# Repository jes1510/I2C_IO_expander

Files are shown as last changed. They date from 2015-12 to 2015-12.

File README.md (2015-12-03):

# I2C_IO_expander

Designed by Jesse Merritt www.github.com/jes1510 December 2, 2015

This design is free software: you can redistribute it and/or modify it under the terms of the GNU General Public License as published by the Free Software Foundation, either version 3 of the License, or (at your option) any later version.

This program is distributed in the hope that it will be useful, but WITHOUT ANY WARRANTY; without even the implied warranty of MERCHANTABILITY or FITNESS FOR A PARTICULAR PURPOSE. See the GNU General Public License for more details.

You should have received a copy of the GNU General Public License along with this program. If not, see <http://www.gnu.org/licenses/

This is an I2C IO expander board that will add 16 pins of IO to a micro controller over I2C.  The IC used allows up to 8 devices on a bus so they can be daisy chained using common RJ11 (telephone) patch cables, allowing a max of 128 pins of IO.  The address is configurable along with terminations and interrupt destinations.

You can assume that I have no idea what I am doing and therefor am not responsible for any damage or negative consequences for using anything from this project. It may destroy all of your equipment and burn down your house.

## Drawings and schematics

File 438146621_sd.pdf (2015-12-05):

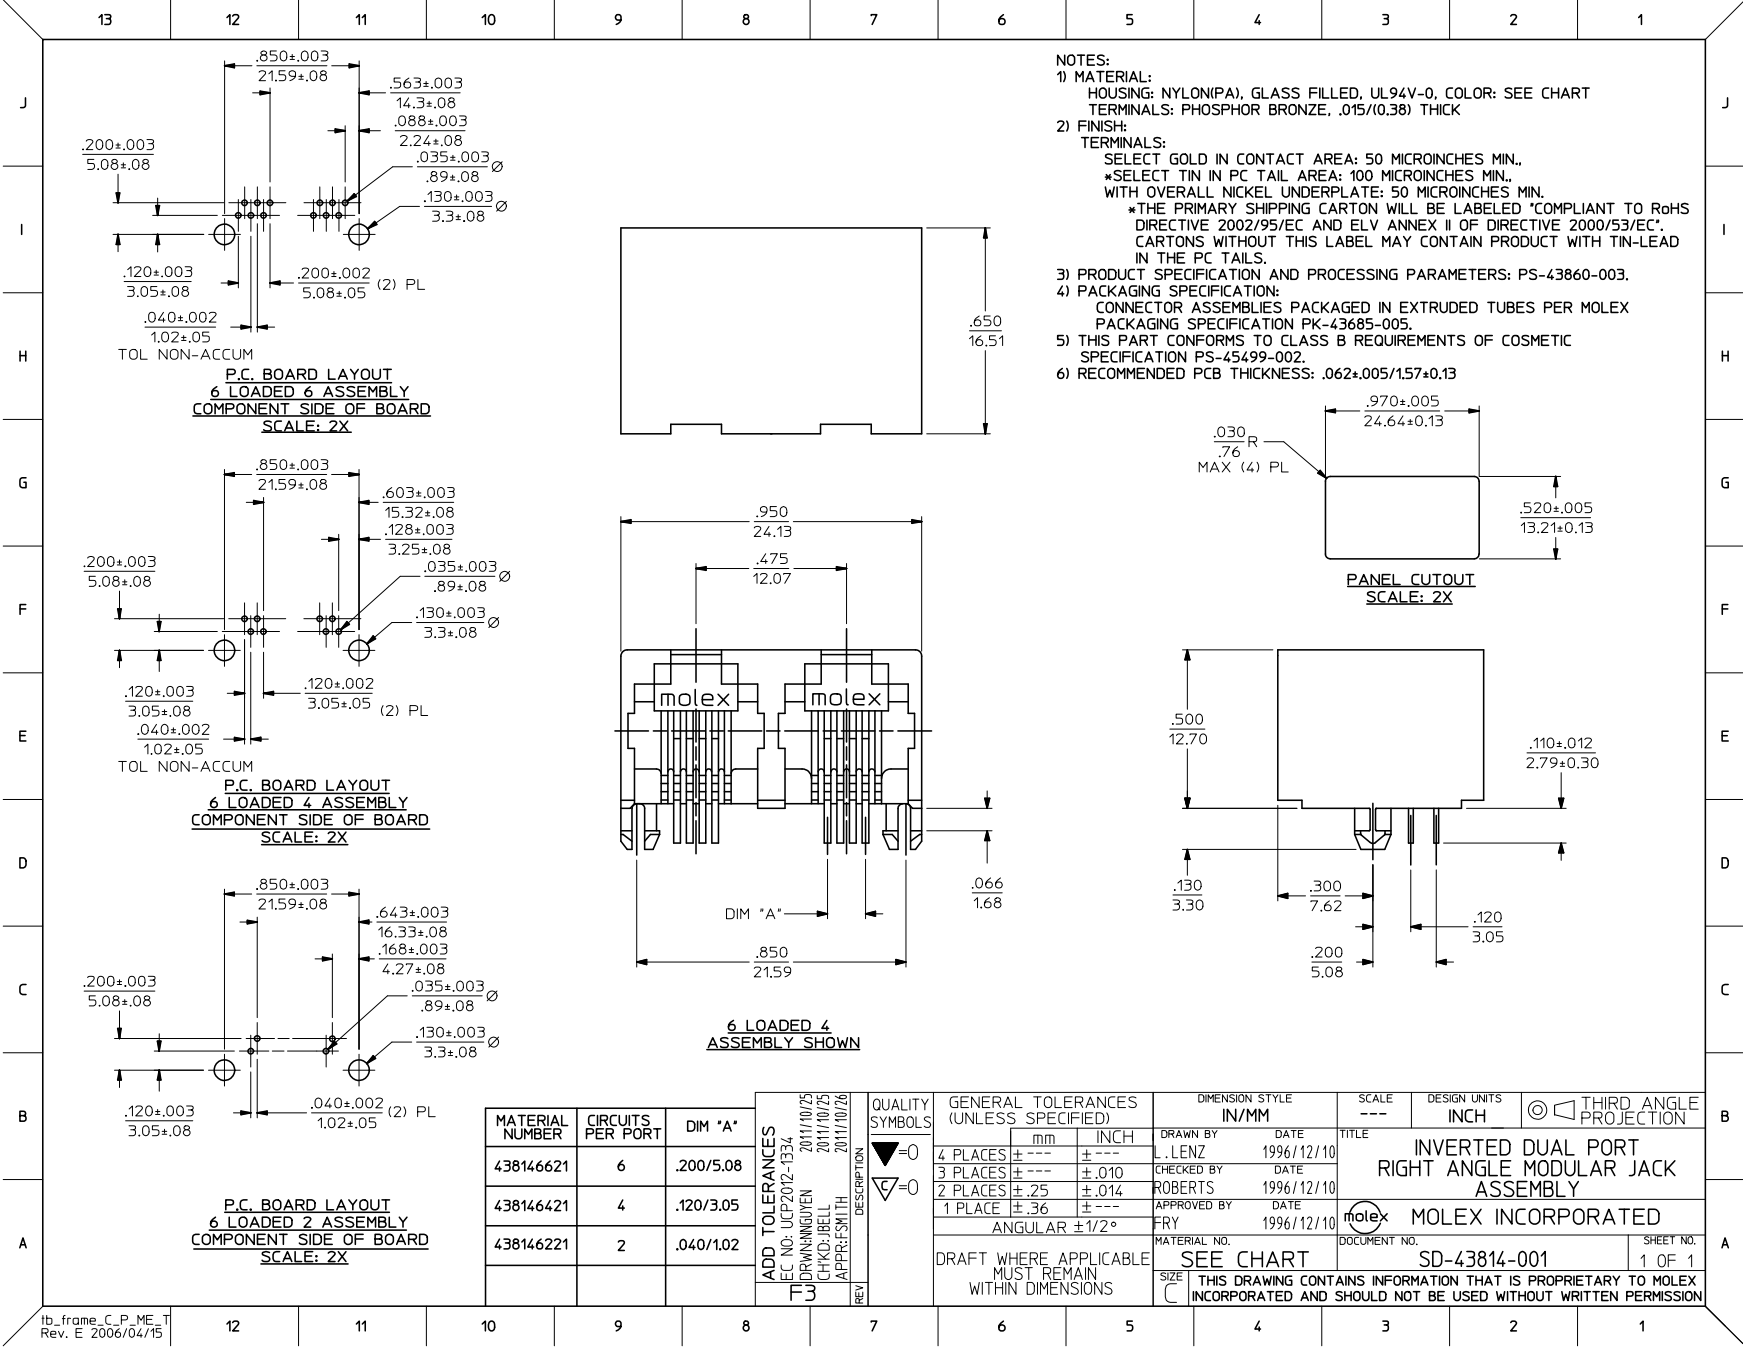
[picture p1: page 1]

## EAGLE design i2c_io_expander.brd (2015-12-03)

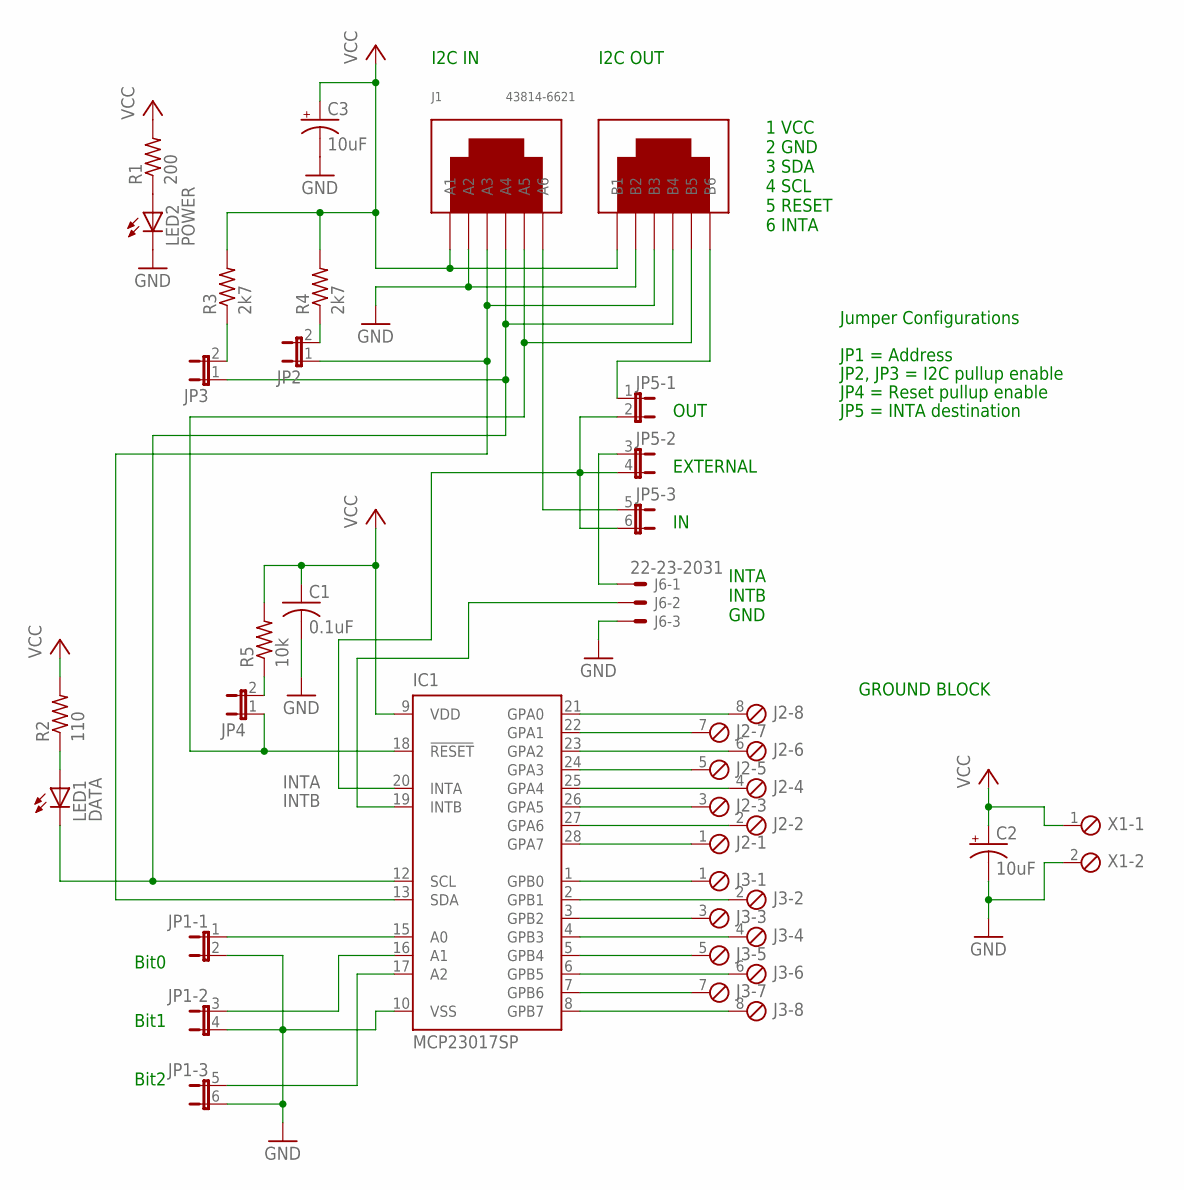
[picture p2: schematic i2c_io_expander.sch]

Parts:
C1: 0.1uF; C025-025X050
C2, C3: 10uF; E5-6
IC1: MCP23017SP; DIL28-3
J1: 43814-6621; MPN 43814-6621
J2, J3: MPT8; 8POL254; MPN 1725711
J6: 22-23-2031
JP1, JP5: JP3QE; JP3Q
JP2, JP3, JP4: JP1E; JP1
LED1: DATA; SMARTLED-TTW
LED2: POWER; SMARTLED-TTW
R1: 200; R0603
R2: 110; R0603
R3, R4: 2k7; R0603
R5: 10k; R0603
X1: MPT2; 2POL254

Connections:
GND: C1.2, C2.-, C3.-, IC1.10 (VSS), J1.A2, J1.B2, J6.3, JP1.2, JP1.4 (2), JP1.6 (2), LED2.C@1 (C), X1.2
INTA: IC1.20 (INTA), JP5.2, JP5.4 (2), JP5.6 (2)
INTB: IC1.19 (INTB), J6.2
unnamed: IC1.15 (A0), JP1.1
unnamed: IC1.16 (A1), JP1.3 (1)
unnamed: IC1.17 (A2), JP1.5 (1)
unnamed: LED2.A@1 (A), R1.1
unnamed: J1.B6, JP5.1
unnamed: JP3.2, R3.1
unnamed: JP4.2, R5.1
unnamed: J6.1, JP5.3 (1)
unnamed: JP2.2, R4.1
unnamed: LED1.A@1 (A), R2.1
unnamed: IC1.28 (GPA7), J2.1
unnamed: IC1.27 (GPA6), J2.2
unnamed: IC1.26 (GPA5), J2.3
unnamed: J1.A6, JP5.5 (1)
unnamed: IC1.25 (GPA4), J2.4
unnamed: IC1.24 (GPA3), J2.5
unnamed: IC1.23 (GPA2), J2.6
unnamed: IC1.22 (GPA1), J2.7
unnamed: IC1.21 (GPA0), J2.8
unnamed: IC1.1 (GPB0), J3.1
unnamed: IC1.2 (GPB1), J3.2
unnamed: IC1.3 (GPB2), J3.3
unnamed: IC1.4 (GPB3), J3.4
unnamed: IC1.5 (GPB4), J3.5
unnamed: IC1.6 (GPB5), J3.6
unnamed: IC1.7 (GPB6), J3.7
unnamed: IC1.8 (GPB7), J3.8
RESET: IC1.18 (!RESET), J1.A5, J1.B5, JP4.1
SCL: IC1.12 (SCL), J1.A4, J1.B4, JP3.1, LED1.C@1 (C)
SDA: IC1.13 (SDA), J1.A3, J1.B3, JP2.1
VCC: C1.1, C2.+, C3.+, IC1.9 (VDD), J1.A1, J1.B1, R1.2, R2.2, R3.2, R4.2, R5.2, X1.1

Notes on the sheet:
JP4 = Reset pullup enable
1 VCC 2 GND 3 SDA 4 SCL 5 RESET 6 INTA
I2C IN
I2C OUT
OUT
EXTERNAL
JP2, JP3 = I2C pullup enable
JP1 = Address
JP5 = INTA destination
Jumper Configurations
INTA INTB GND
Bit0 Bit1 Bit2
GROUND BLOCK

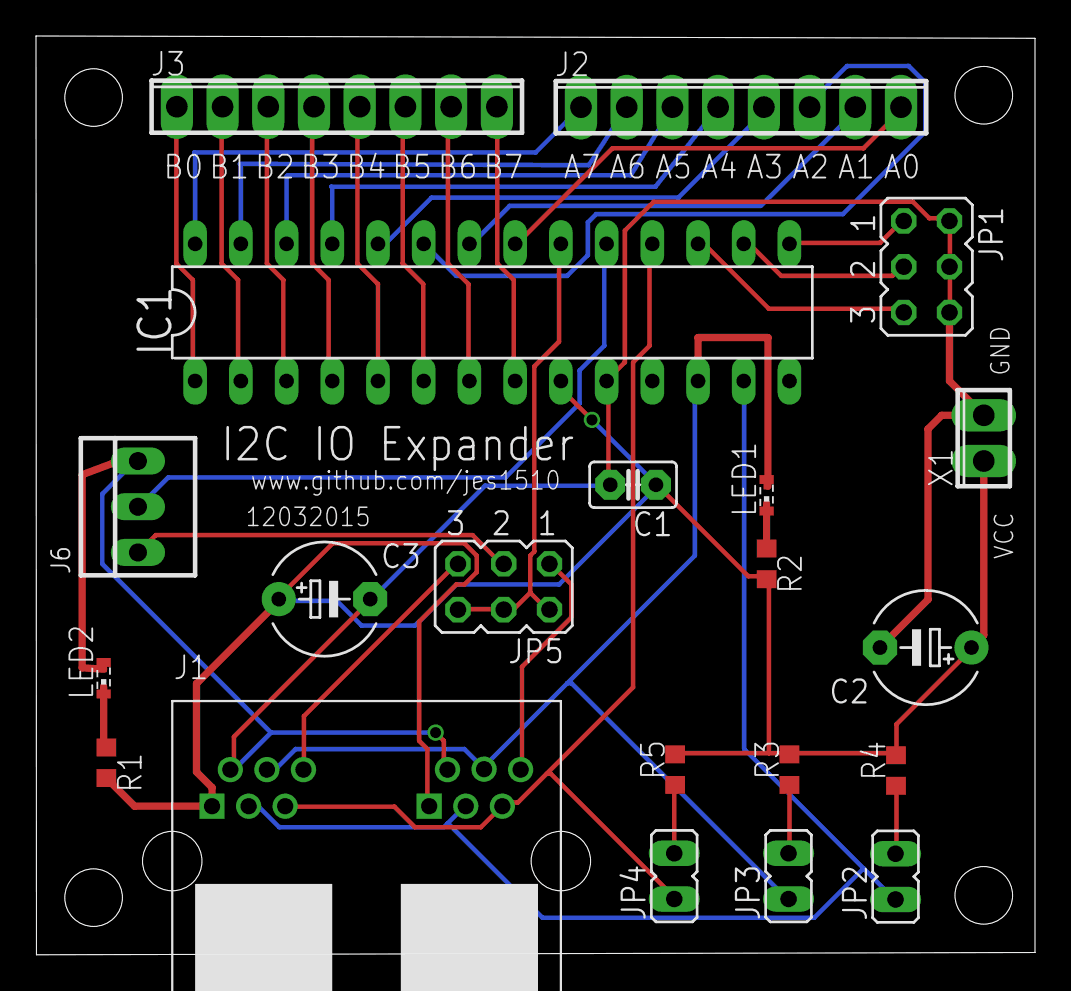
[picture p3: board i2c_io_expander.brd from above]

Board: 2 copper layers, 55.5 x 51.0 mm, 21 parts (0 on the bottom side), 34 nets.

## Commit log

2015-12-03 Added contact info and rev # to silkscreen Added VCC and GND designator to silkscreen
    [i2c_io_expander.brd, i2c_io_expander.sch]
2015-12-27 Added title block Added additional text to claify jumper settings
    [i2c_io_expander.sch]
